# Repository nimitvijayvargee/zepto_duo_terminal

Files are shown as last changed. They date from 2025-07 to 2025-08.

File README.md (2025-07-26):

# zepto_duo_terminal
An old school-style VGA output terminal PC!
The PC is powered by two Raspberry Pi Picos. One of the Pico handles the main processing and the keyboard matrix (CPU Pico) and the other Pico handles the VGA Output and the conversion between text to pixels (GPU Pico). The Picos can be replaced with any Pin-compatible version.
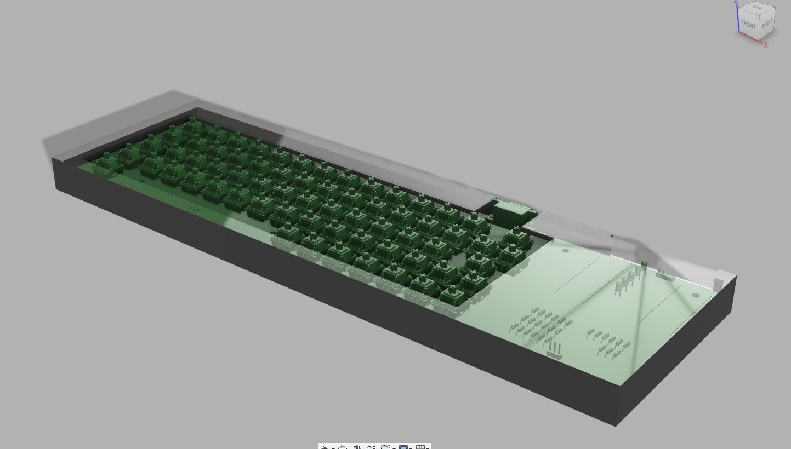
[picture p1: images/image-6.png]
Fusion Render

## VGA DAC
The GPU Pico is connected to a Resistor DAC that outputs VGA compatible voltage values. There are 5 bits of resolution for each colour channel (RGB555), which allows for 32K colours. The values for the DAC are as 500, 1K, 2K, and 5.1K (commonly used values).
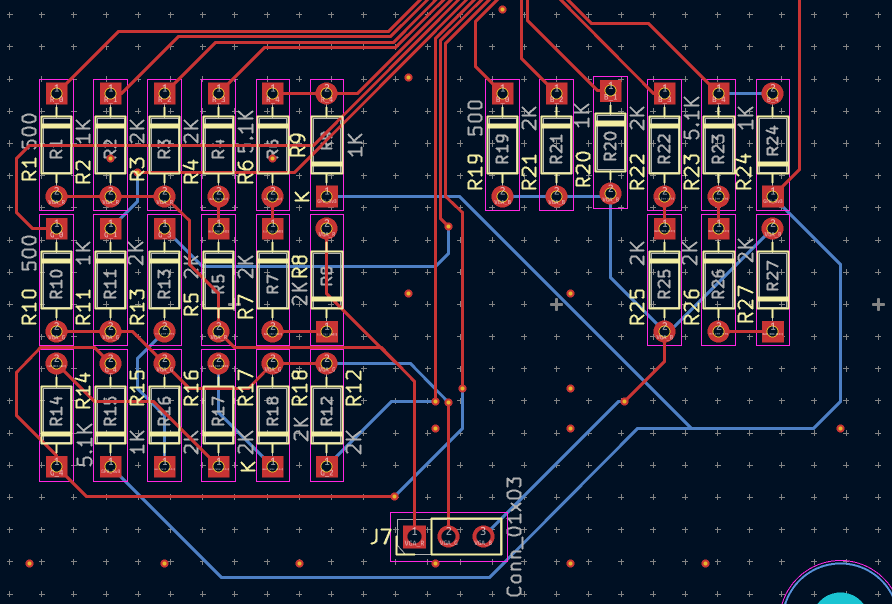
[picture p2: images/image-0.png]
VGADAC


## Keyboard Matrix 
The Keyboard matrix is composed of 8 Rows and 8 Columns, following an ortholinear keyboard layout. Sticky (toggle) keys is also enabled by default to make using the keyboard easier. The keyboard features a "Special" key instead of the commly used Fn or GUI keys. The keycaps are all custom becuase of their specific use case and the unorthodox ortholinear layout.

# Pictures
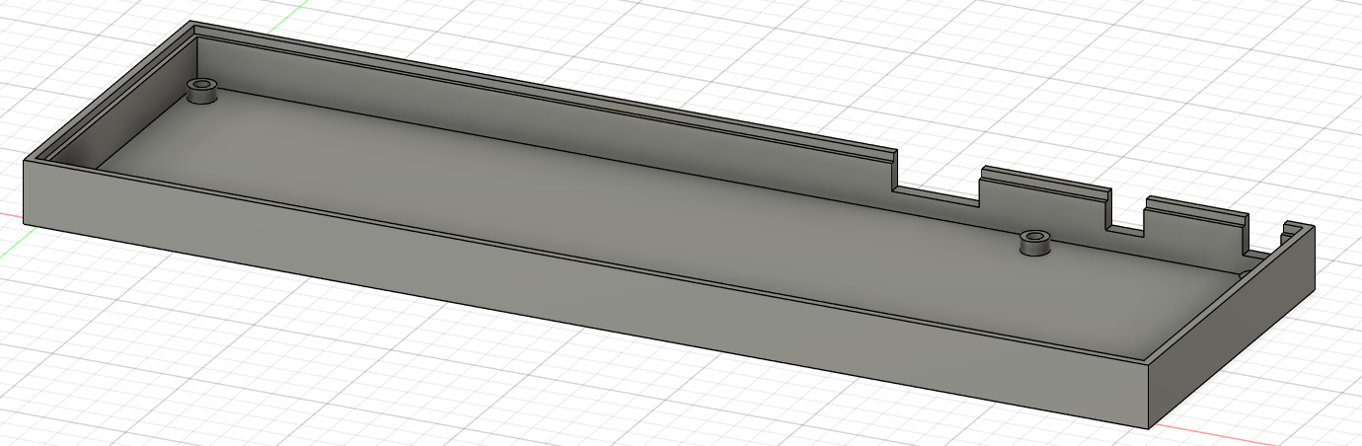
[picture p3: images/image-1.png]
Case

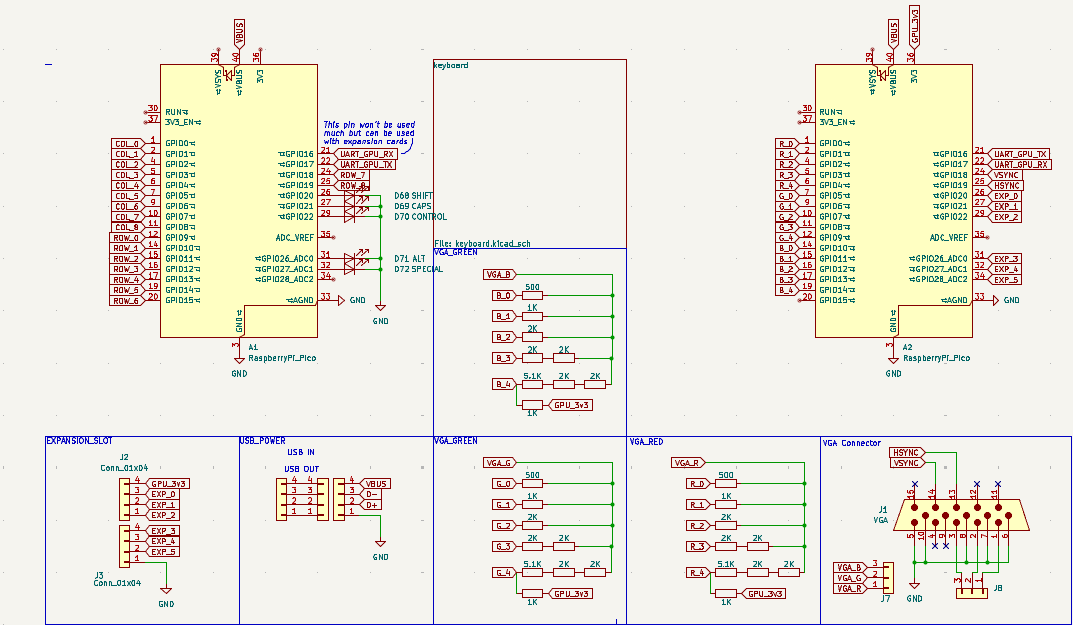
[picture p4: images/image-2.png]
Schematic

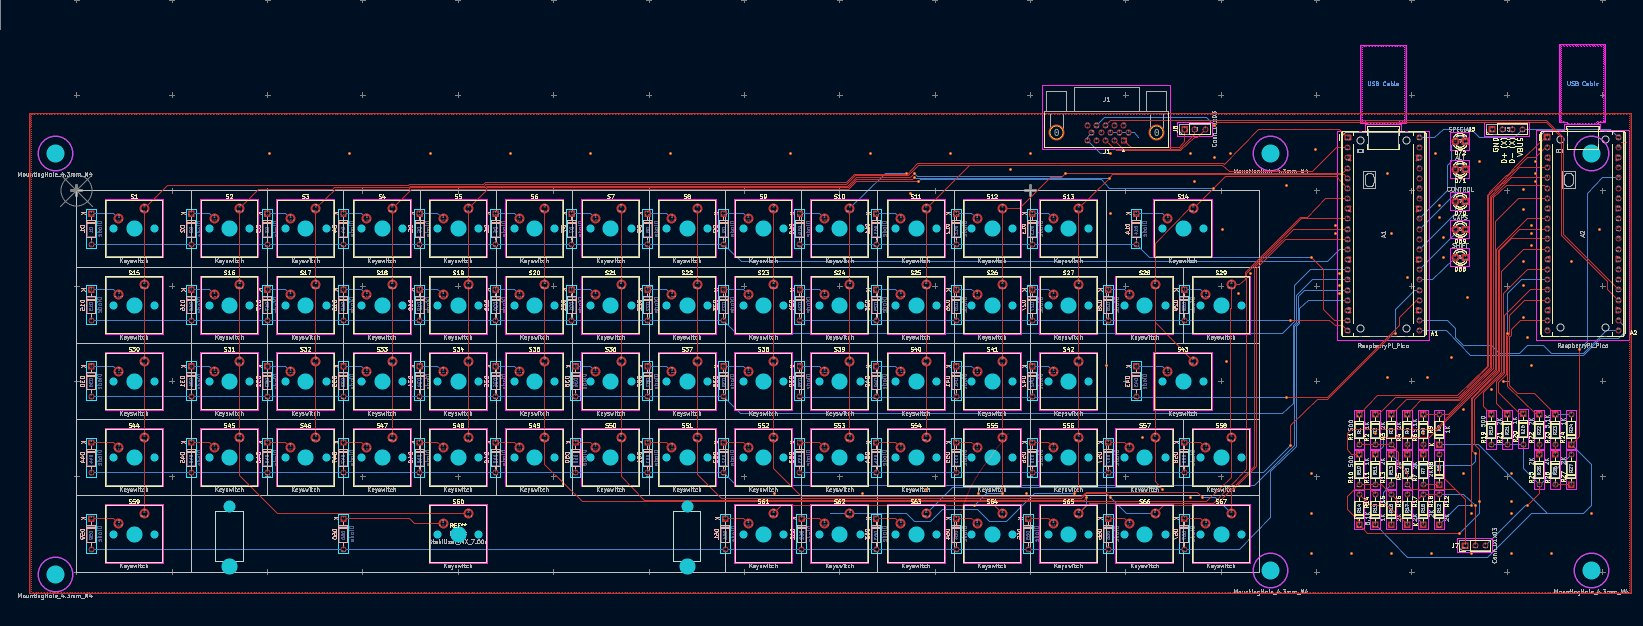
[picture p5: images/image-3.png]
PCB


# BOM
|Item |Cost|
|---|----|
|DB-15 VGA Connector |[1](https://roboticsdna.in/product/db15-female-pcb-mount-right-angle-connector-2-pcs/) |
|1N4148 Diodes |[5](https://roboticsdna.in/product/diode-1n4148/) |
|LEDs |[0.5](https://roboticsdna.in/product/super-bright-white-led-3mm-1000-pcs/) |
|Raspberry Pi Pico (x2)|[10](https://roboticsdna.in/product/raspberry-pi-pico/)  |
|Headers |[0.5](https://roboticsdna.in/product/40x1-10mm-2-5mm-pitch-burg-strip-male-straight-brass-high-quality-pack-of-5/) |
|PCB (400x120mm) |[75](https://www.pcbpower.com/page/pcb-fabrication)  |
|Case + Keycaps | |
|Switches |[20](https://stackskb.com/store/akko-v3-cream-blue-pro-switch-pack-of-45/)  |
|Solder |[5](https://roboticsdna.in/product/dl-premium-solder-wire-63-37-22-swg-50gm/)  |
|TOTAL |117 |

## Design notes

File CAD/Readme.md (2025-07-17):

The Case File is for the whole system
The keycap files are for each individual keycaps. 
| Keycap | Quantity |
|---|---|
| 1u | 59 |
| 1.5u | 5 |
| 2u | 2 |
| 7u | 1 |

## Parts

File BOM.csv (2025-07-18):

Item | Cost
DB-15 VGA Connector | 1
1N4148 Diodes | 5
LEDs | 0.5
Raspberry Pi Pico (x2) | 10
Headers | 0.5
PCB (400x120mm) | 75
Case + Keycaps
Switches | 20
Solder | 3
TOTAL | 115

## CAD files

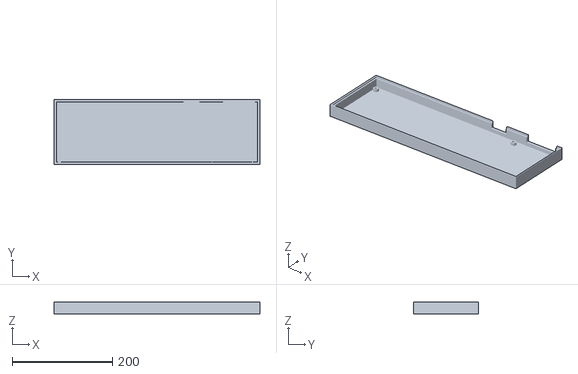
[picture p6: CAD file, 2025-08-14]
CAD/case.stl
410.0 x 130.0 x 23.0

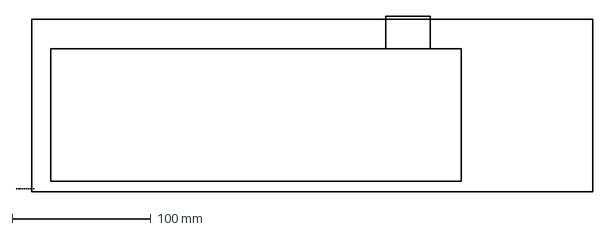
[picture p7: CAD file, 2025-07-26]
CAD/acrylic.dxf
415.0 x 126.0 mm

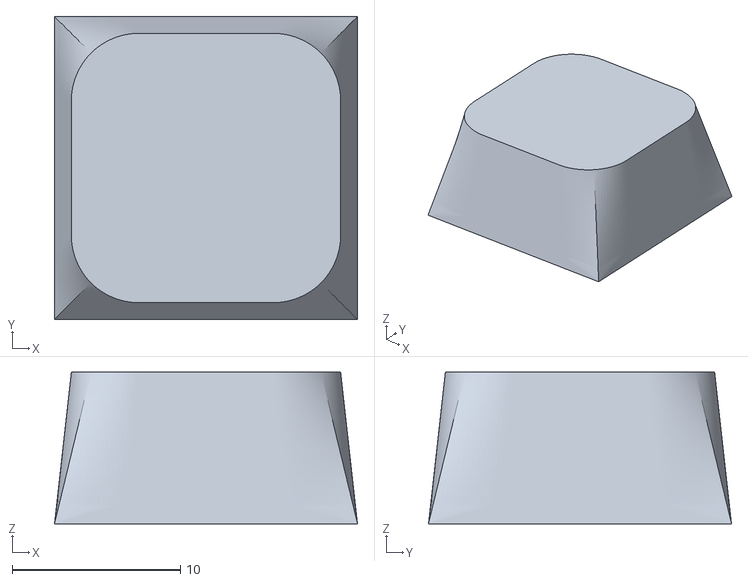
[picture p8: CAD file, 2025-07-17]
CAD/keycap1u.stl
18.0 x 18.0 x 9.00

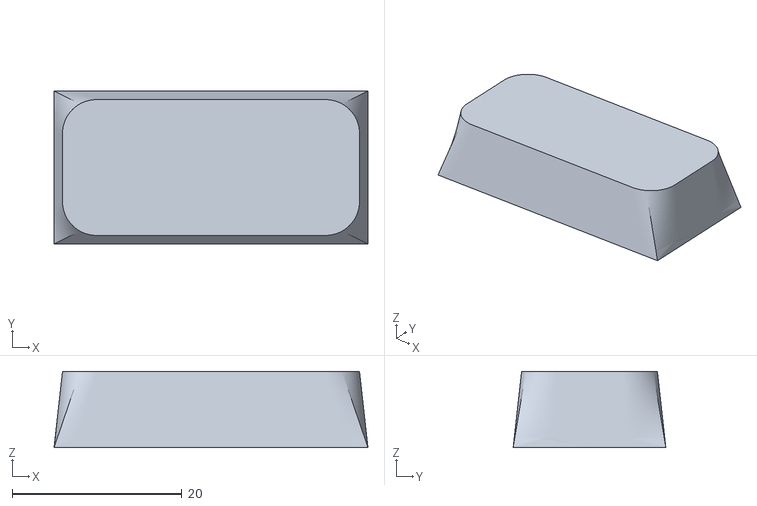
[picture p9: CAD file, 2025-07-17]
CAD/keycap2u.stl
37.0 x 18.0 x 9.00

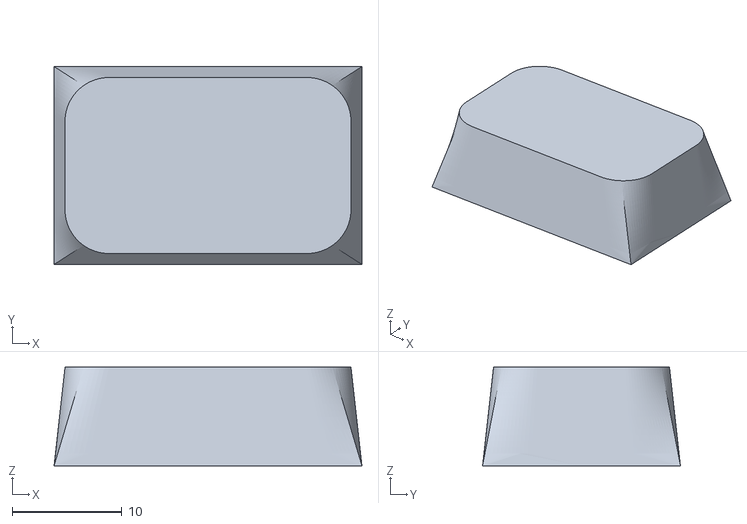
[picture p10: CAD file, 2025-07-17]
CAD/keycap1.5u.stl
28.0 x 18.0 x 9.00

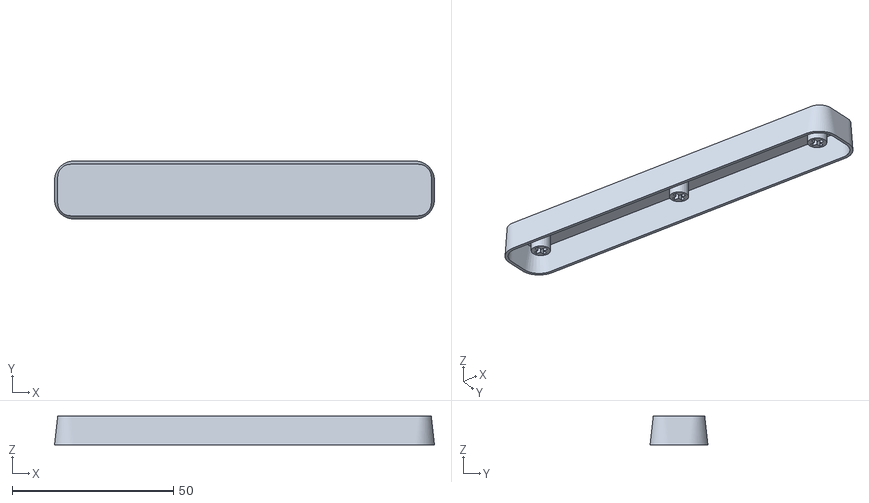
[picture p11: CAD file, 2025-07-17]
CAD/keycap7u.stl
118.0 x 18.0 x 9.00

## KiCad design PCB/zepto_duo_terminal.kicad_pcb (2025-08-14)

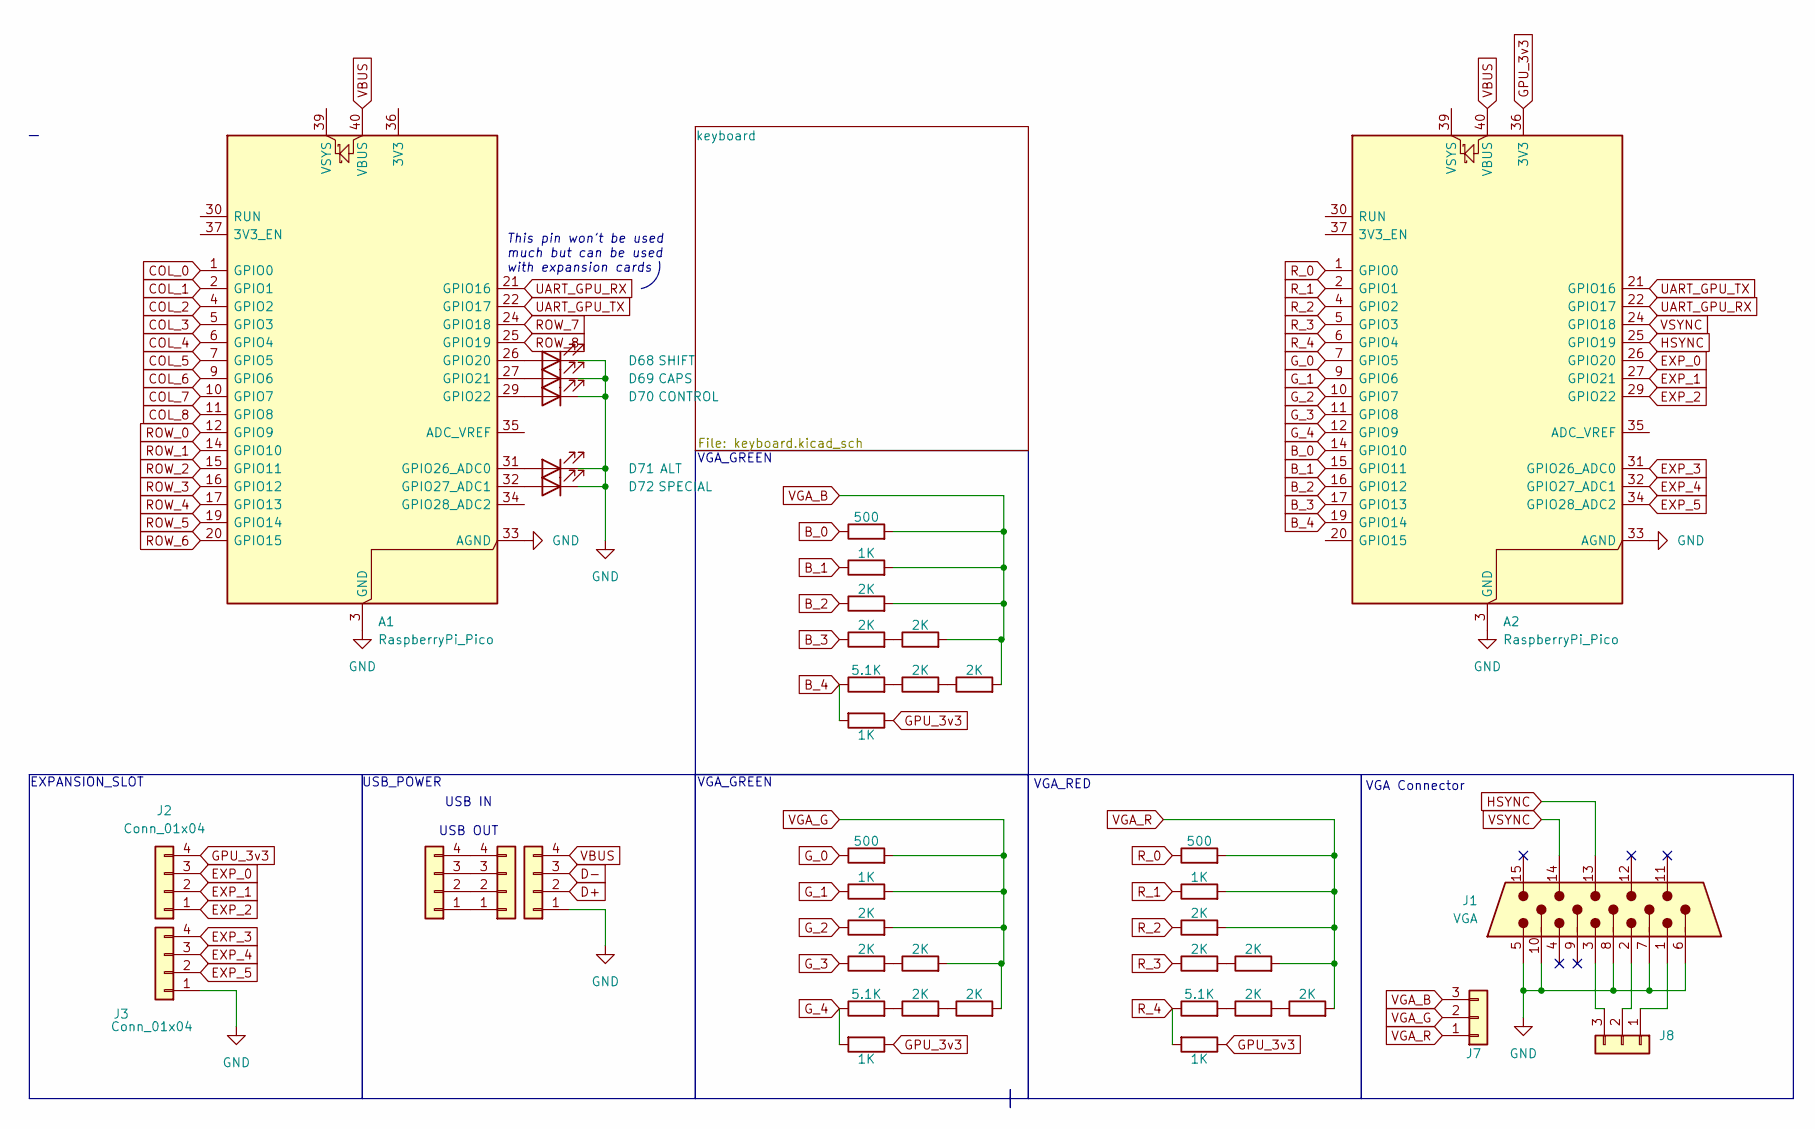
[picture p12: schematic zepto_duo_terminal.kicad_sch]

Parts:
A1, A2: RaspberryPi_Pico; RaspberryPi_Pico_Common_THT
D68: SHIFT; LED_D3.0mm
D69: CAPS; LED_D3.0mm
D70: CONTROL; LED_D3.0mm
D71: ALT; LED_D3.0mm
D72: SPECIAL; LED_D3.0mm
J1: VGA; DSUB-15-HD_Pins_Horizontal_P2.29x1.90mm_EdgePinOffset3.03mm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
J2, J3, J4, J5, J6: Conn_01x04; PinHeader_1x04_P2.54mm_Vertical
J7, J8: Conn_01x03; PinHeader_1x03_P2.54mm_Vertical
R1, R10, R19: 500; D_DO-35_SOD27_P7.62mm_Horizontal
R2, R9, R11, R15, R20, R24: 1K; D_DO-35_SOD27_P7.62mm_Horizontal
R3, R4, R5, R7, R8, R12, R13, R16, R17, R18, R21, R22, R25, R26, R27: 2K; D_DO-35_SOD27_P7.62mm_Horizontal
R6, R14, R23: 5.1K; D_DO-35_SOD27_P7.62mm_Horizontal

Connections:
B_0: A2.14 (GPIO10), R19.1
B_1: A2.15 (GPIO11), R20.1
B_2: A2.16 (GPIO12), R21.1
B_3: A2.17 (GPIO13), R22.1
B_4: A2.19 (GPIO14), R23.1, R24.2
COL_0: A1.1 (GPIO0); also elsewhere on the board
COL_1: A1.2 (GPIO1); also elsewhere on the board
COL_2: A1.4 (GPIO2); also elsewhere on the board
COL_3: A1.5 (GPIO3); also elsewhere on the board
COL_4: A1.6 (GPIO4); also elsewhere on the board
COL_5: A1.7 (GPIO5); also elsewhere on the board
COL_6: A1.9 (GPIO6); also elsewhere on the board
COL_7: A1.10 (GPIO7); also elsewhere on the board
COL_8: A1.11 (GPIO8); also elsewhere on the board
D+: J5.2
D-: J5.3
EXP_0: A2.26 (GPIO20), J2.3
EXP_1: A2.27 (GPIO21), J2.2
EXP_2: A2.29 (GPIO22), J2.1
EXP_3: A2.31 (GPIO26_ADC0), J3.4
EXP_4: A2.32 (GPIO27_ADC1), J3.3
EXP_5: A2.34 (GPIO28_ADC2), J3.2
GND: A1.3 (GND), A1.8 (GND), A1.13 (GND), A1.18 (GND), A1.23 (GND), A1.28 (GND), A1.33 (AGND), A1.38 (GND), A2.3 (GND), A2.8 (GND), A2.13 (GND), A2.18 (GND), A2.23 (GND), A2.28 (GND), A2.33 (AGND), A2.38 (GND), D68.1 (K), D69.1 (K), D70.1 (K), D71.1 (K), D72.1 (K), J1.5, J1.6, J1.7, J1.8, J1.10, J3.1, J5.1
GPU_3v3: A2.36 (3V3), J2.4, R9.1, R15.1, R24.1
G_0: A2.7 (GPIO5), R10.1
G_1: A2.9 (GPIO6), R11.1
G_2: A2.10 (GPIO7), R12.1
G_3: A2.11 (GPIO8), R13.1
G_4: A2.12 (GPIO9), R14.1, R15.2
HSYNC: A2.25 (GPIO19), J1.13
unnamed: A1.26 (GPIO20), D68.2 (A)
unnamed: A1.27 (GPIO21), D69.2 (A)
unnamed: A1.29 (GPIO22), D70.2 (A)
unnamed: A1.31 (GPIO26_ADC0), D71.2 (A)
unnamed: A1.32 (GPIO27_ADC1), D72.2 (A)
unnamed: J4.1, J6.1
unnamed: J4.2, J6.2
unnamed: J4.3, J6.3
unnamed: J4.4, J6.4
unnamed: J1.1, J8.1
unnamed: J1.2, J8.2
unnamed: J1.3, J8.3
unnamed: R4.2, R5.1
unnamed: R6.2, R7.1
unnamed: R7.2, R8.1
unnamed: R13.2, R16.1
unnamed: R14.2, R17.1
unnamed: R17.2, R18.1
unnamed: R22.2, R25.1
unnamed: R23.2, R26.1
unnamed: R26.2, R27.1
ROW_0: A1.12 (GPIO9); also elsewhere on the board
ROW_1: A1.14 (GPIO10); also elsewhere on the board
ROW_2: A1.15 (GPIO11); also elsewhere on the board
ROW_3: A1.16 (GPIO12); also elsewhere on the board
ROW_4: A1.17 (GPIO13); also elsewhere on the board
ROW_5: A1.19 (GPIO14); also elsewhere on the board
ROW_6: A1.20 (GPIO15); also elsewhere on the board
ROW_7: A1.24 (GPIO18); also elsewhere on the board
ROW_8: A1.25 (GPIO19); also elsewhere on the board
R_0: A2.1 (GPIO0), R1.1
R_1: A2.2 (GPIO1), R2.1
R_2: A2.4 (GPIO2), R3.1
R_3: A2.5 (GPIO3), R4.1
R_4: A2.6 (GPIO4), R6.1, R9.2
UART_GPU_RX: A1.21 (GPIO16), A2.22 (GPIO17)
UART_GPU_TX: A1.22 (GPIO17), A2.21 (GPIO16)
VBUS: A1.40 (VBUS), A2.40 (VBUS), J5.4
VGA_B: J7.3, R19.2, R20.2, R21.2, R25.2, R27.2
VGA_G: J7.2, R10.2, R11.2, R12.2, R16.2, R18.2
VGA_R: J7.1, R1.2, R2.2, R3.2, R5.2, R8.2
VSYNC: A2.24 (GPIO18), J1.14

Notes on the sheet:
VGA Connector
USB_POWER
USB IN USB OUT
VGA_RED
This pin won't be used much but can be used with expansion cards
EXPANSION_SLOT
VGA_GREEN

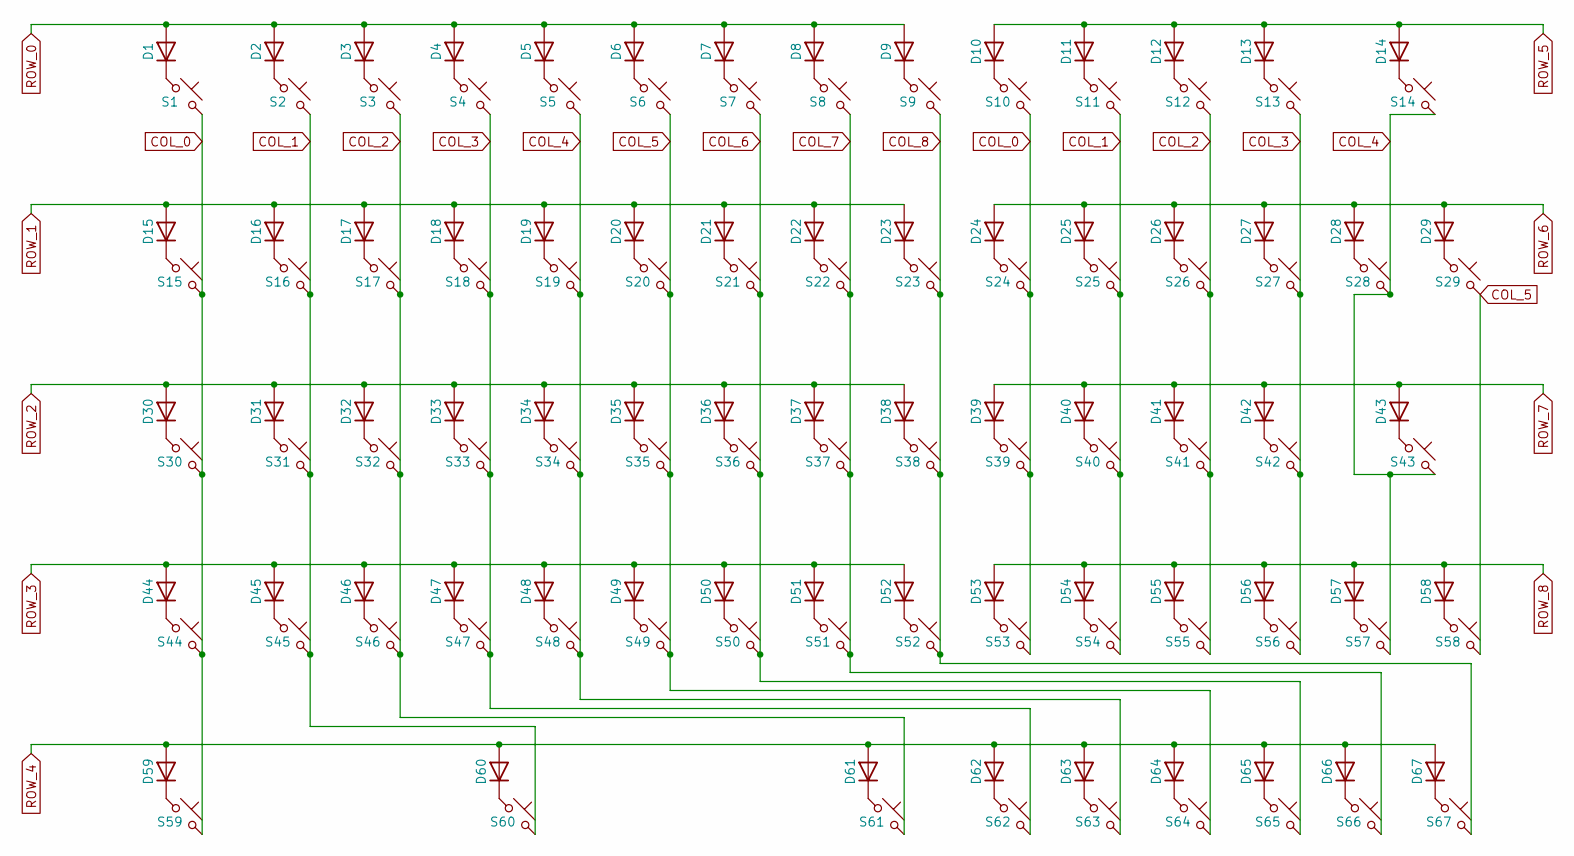
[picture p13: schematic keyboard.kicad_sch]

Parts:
D1, D2, D3, D4, D5, D6, D7, D8, D9, D10, D11, D12, D13, D14, D15, D16, D17, D18, D19, D20, D21, D22, D23, D24, D25, D26, D27, D28, D29, D30, D31, D32, D33, D34, D35, D36, D37, D38, D39, D40, D41, D42, D43, D44, D45, D46, D47, D48, D49, D50, D51, D52, D53, D54, D55, D56, D57, D58, D59, D60, D61, D62, D63, D64, D65, D66, D67: Diode; D_DO-35_SOD27_P7.62mm_Horizontal
S1, S15, S30, S44, S59: Keyswitch; MX_PCB_1.50u
S2, S3, S4, S5, S6, S7, S8, S9, S10, S11, S12, S13, S16, S17, S18, S19, S20, S21, S22, S23, S24, S25, S26, S27, S28, S29, S31, S32, S33, S34, S35, S36, S37, S38, S39, S40, S41, S42, S45, S46, S47, S48, S49, S50, S51, S52, S53, S54, S55, S56, S57, S58, S62, S63, S64, S65, S66, S67: Keyswitch; MX_PCB_1.00u
S14, S43: Keyswitch; MX_PCB_2.00u
S60: Keyswitch; MX_PCB_6.25u
S61: Keyswitch; MX_PCB_1.25u

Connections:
COL_0: S1.2, S10.2, S15.2, S24.2, S30.2, S39.2, S44.2, S53.2, S59.2; also elsewhere on the board
COL_1: S2.2, S11.2, S16.2, S25.2, S31.2, S40.2, S45.2, S54.2, S60.2; also elsewhere on the board
COL_2: S3.2, S12.2, S17.2, S26.2, S32.2, S41.2, S46.2, S55.2, S61.2; also elsewhere on the board
COL_3: S4.2, S13.2, S18.2, S27.2, S33.2, S42.2, S47.2, S56.2, S62.2; also elsewhere on the board
COL_4: S5.2, S14.2, S19.2, S28.2, S34.2, S43.2, S48.2, S57.2, S63.2; also elsewhere on the board
COL_5: S6.2, S20.2, S29.2, S35.2, S49.2, S58.2, S64.2; also elsewhere on the board
COL_6: S7.2, S21.2, S36.2, S50.2, S65.2; also elsewhere on the board
COL_7: S8.2, S22.2, S37.2, S51.2, S66.2; also elsewhere on the board
COL_8: S9.2, S23.2, S38.2, S52.2, S67.2; also elsewhere on the board
unnamed: D1.1 (K), S1.1
unnamed: D2.1 (K), S2.1
unnamed: D3.1 (K), S3.1
unnamed: D4.1 (K), S4.1
unnamed: D5.1 (K), S5.1
unnamed: D6.1 (K), S6.1
unnamed: D7.1 (K), S7.1
unnamed: D8.1 (K), S8.1
unnamed: D9.1 (K), S9.1
unnamed: D10.1 (K), S10.1
unnamed: D11.1 (K), S11.1
unnamed: D12.1 (K), S12.1
unnamed: D13.1 (K), S13.1
unnamed: D14.1 (K), S14.1
unnamed: D15.1 (K), S15.1
unnamed: D16.1 (K), S16.1
unnamed: D17.1 (K), S17.1
unnamed: D18.1 (K), S18.1
unnamed: D19.1 (K), S19.1
unnamed: D20.1 (K), S20.1
unnamed: D21.1 (K), S21.1
unnamed: D22.1 (K), S22.1
unnamed: D23.1 (K), S23.1
unnamed: D24.1 (K), S24.1
unnamed: D25.1 (K), S25.1
unnamed: D26.1 (K), S26.1
unnamed: D27.1 (K), S27.1
unnamed: D28.1 (K), S28.1
unnamed: D29.1 (K), S29.1
unnamed: D30.1 (K), S30.1
unnamed: D31.1 (K), S31.1
unnamed: D32.1 (K), S32.1
unnamed: D33.1 (K), S33.1
unnamed: D34.1 (K), S34.1
unnamed: D35.1 (K), S35.1
unnamed: D36.1 (K), S36.1
unnamed: D37.1 (K), S37.1
unnamed: D38.1 (K), S38.1
unnamed: D39.1 (K), S39.1
unnamed: D40.1 (K), S40.1
unnamed: D41.1 (K), S41.1
unnamed: D42.1 (K), S42.1
unnamed: D43.1 (K), S43.1
unnamed: D44.1 (K), S44.1
unnamed: D45.1 (K), S45.1
unnamed: D46.1 (K), S46.1
unnamed: D47.1 (K), S47.1
unnamed: D48.1 (K), S48.1
unnamed: D49.1 (K), S49.1
unnamed: D50.1 (K), S50.1
unnamed: D51.1 (K), S51.1
unnamed: D52.1 (K), S52.1
unnamed: D53.1 (K), S53.1
unnamed: D54.1 (K), S54.1
unnamed: D55.1 (K), S55.1
unnamed: D56.1 (K), S56.1
unnamed: D57.1 (K), S57.1
unnamed: D58.1 (K), S58.1
unnamed: D59.1 (K), S59.1
unnamed: D60.1 (K), S60.1
unnamed: D61.1 (K), S61.1
unnamed: D62.1 (K), S62.1
unnamed: D63.1 (K), S63.1
unnamed: D64.1 (K), S64.1
unnamed: D65.1 (K), S65.1
unnamed: D66.1 (K), S66.1
unnamed: D67.1 (K), S67.1
ROW_0: D1.2 (A), D2.2 (A), D3.2 (A), D4.2 (A), D5.2 (A), D6.2 (A), D7.2 (A), D8.2 (A), D9.2 (A); also elsewhere on the board
ROW_1: D15.2 (A), D16.2 (A), D17.2 (A), D18.2 (A), D19.2 (A), D20.2 (A), D21.2 (A), D22.2 (A), D23.2 (A); also elsewhere on the board
ROW_2: D30.2 (A), D31.2 (A), D32.2 (A), D33.2 (A), D34.2 (A), D35.2 (A), D36.2 (A), D37.2 (A), D38.2 (A); also elsewhere on the board
ROW_3: D44.2 (A), D45.2 (A), D46.2 (A), D47.2 (A), D48.2 (A), D49.2 (A), D50.2 (A), D51.2 (A), D52.2 (A); also elsewhere on the board
ROW_4: D59.2 (A), D60.2 (A), D61.2 (A), D62.2 (A), D63.2 (A), D64.2 (A), D65.2 (A), D66.2 (A), D67.2 (A); also elsewhere on the board
ROW_5: D10.2 (A), D11.2 (A), D12.2 (A), D13.2 (A), D14.2 (A); also elsewhere on the board
ROW_6: D24.2 (A), D25.2 (A), D26.2 (A), D27.2 (A), D28.2 (A), D29.2 (A); also elsewhere on the board
ROW_7: D39.2 (A), D40.2 (A), D41.2 (A), D42.2 (A), D43.2 (A); also elsewhere on the board
ROW_8: D53.2 (A), D54.2 (A), D55.2 (A), D56.2 (A), D57.2 (A), D58.2 (A); also elsewhere on the board

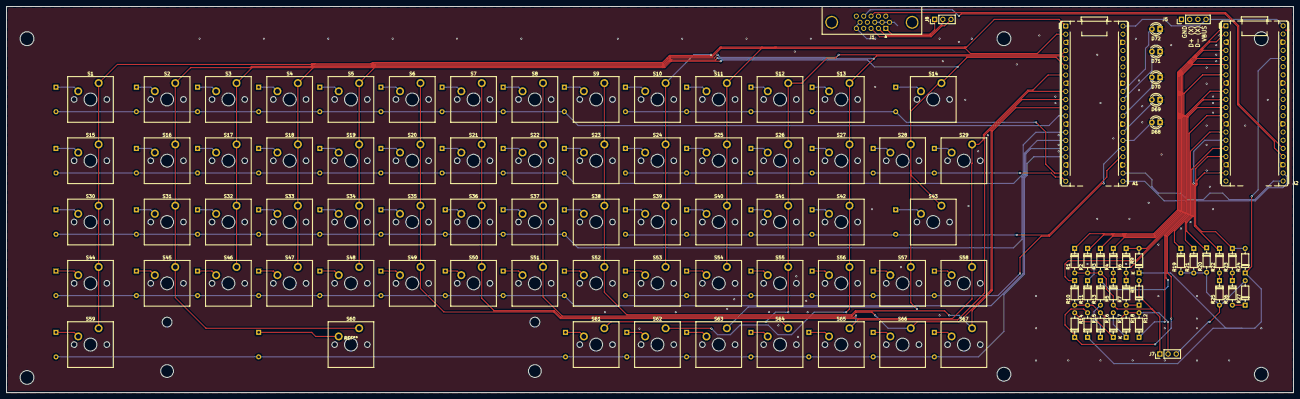
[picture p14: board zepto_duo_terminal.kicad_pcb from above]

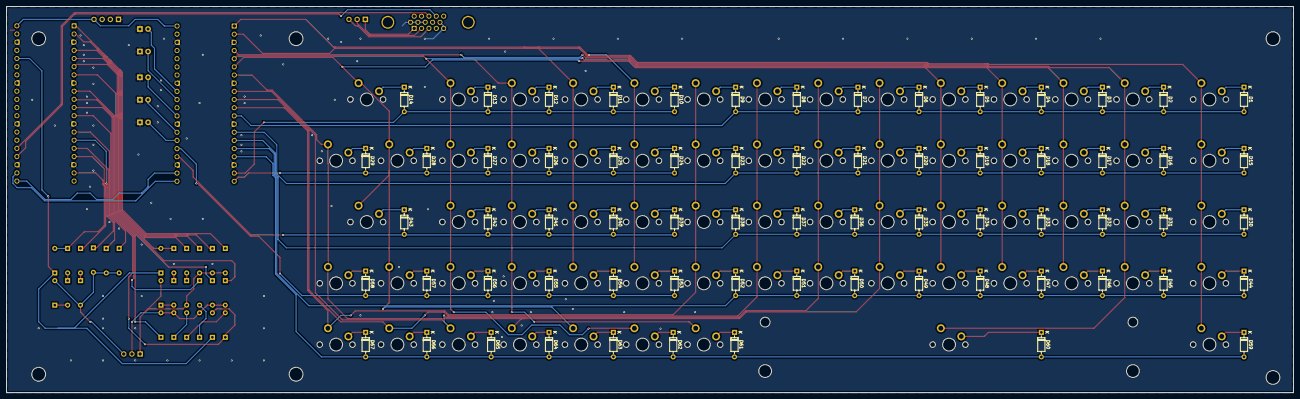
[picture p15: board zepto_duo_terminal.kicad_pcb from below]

Board: 2 copper layers, 400.0 x 120.0 mm, 172 parts (67 on the bottom side), 127 nets.

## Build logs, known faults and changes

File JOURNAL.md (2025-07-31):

---
title: "Zepto Duo Terminal"
author: "nimit vijayvargee"
description: "An all-in-one Terminal PC with two Pi Picos that outputs VGA, all with a a built-in keyboard!"
created_at: "2025-06-24"
---
# Total Time Spent : 26 Hours

# Day 1 - 25th June
Created a sketch and layout for the project, mostly brainstorming

# Day 2 - 26th June
Time Spent: 2hrs <br>
Started reseasrching into VGA with the Pi Pico, and read the Hardware Design docs for VGA pinouts and connections.
The RP2040 Hardware Design docs dedicate a section to the VGA interface over PIO Assembly. After doing some research, I found out about `scanvideo`, which is a Pico SDK PIO Library for implementing scanline video output such as DVI and VGA, which is exactly what I need.


# Day 3 - 27th June
Time Spent: 2hrs <br>
Designed the built-in keyboard, plan to use basic MX keys with an ortholinear layout. Also included sticky-keys indicators because holding keys simultaneously may be difficult to implement. Also laid out the keyboard both in Keyboard Layout Editor. I then added everything to the schematic which was very easy due to the ortholinear keyboard layout. I managed to connect the GPU and CPU Picos over a data bridge, which I intend to be UART.<br>


Time Spent: 3hrs <br>
Today I completed routing the schematic. I also managed to finish laying out the keyboard design and connected all the rows and columns. I then spent some time choosing the footprints for all the components. This PCB is intended to be hand-soldered so I chose THT footprints for the Diodes, Resistors and the LEDs. Because of the custom layout, I was unable to find any useful keycaps (I mean who makes a 1u shift key and a 1.5u escape key), so I will be 3D printing the keycaps. I also designed a few sketches for how I want the case to look like. I want it to be a two-part case, with the top part being acrylic and the bottom part being 3D printed. This will make the green PCB look very cool and show all the various components.



# Day 4 - Day 8 -- 28th June - 1st July 
Time Spent: 8hrs
I placed the footprints into my PCB editor and started moving them around. I added M4 Screw holes for the PCB to attach to the case. I added a header for an expansion slot for later use although I might scrap the feature altogether. I laid out the matrix and the diodes using the MX Grid trick (set your grid size to match the MX size). I also added a little bit of silkscreen to make the PCB have some personality.



# Day 9 - Day 10 -- 2nd July - 3rd July
Time Spent: 3hrs
I rerouted the PCB and moved around the components to make it more compact. I also planned out the keycaps to print. I initially planned to use a 6.25u Spacebar, but since it is the only key that needs that stabilizer, I decided to use a 7u spacebar instead, because I had an extra 7u wire. I managed to redo the layout and routing to accommodate the 7u, which wasn't as hard. I also considered printing the keycaps in offwhite PLA but it isn't as easy to find as black or white, so I will stick to those for now.

# Day 11 - Day 12 -- 10th July - 11th July
Time Spent: 3hrs <br>
Returned to this project after some time. On comparing prices across websites, it was much cheaper to reroute the main board to follow a different layout. The board is now 400x120 (mm) and has more or a Pi500 vibe to it. Most of the layout and routing could be reused but I did decide to redo the resistors for the VGA and remove the expansion card slot



# Day 13 - 14th July
Time Spent: 2hrs <br>
I started working on the CAD. I first sketched out the PCB with the mounting holes then created an area arount it. I extruded everything to a reasonable size and created some renders. I just need to make the keycpas now.

# Day 14 - 15 -- 15th - 16th July
Time Spent: 2hrs <br>
I spent this day just designing the custom keycaps. It was difficult but  when I finished my first 1u keycap, I got into the pace to finish the rest of the keycaps too. The 7u spacebar looks a bit weird but I kinda like the idea of a curved spacebar alongside normal keys. The rounded corners are just somethinng I want to do, although they might attract dust (future me problem lol). \





# Day 15 - 27th July
Time Spent: 1hr <br>
I worked on the code. I am going to use the `adafruit_color_terminal` library for circuitpython to create the terminal, but for the video output I need to decide between `scanvideo` (C SDK) or writing it in PIO-ASM on Circuitpython. I did some testing of the code on a spare ST7735R screen I had lying around. Afterwards, I can do it properly on a monitor.
I also made a render for the updated case!


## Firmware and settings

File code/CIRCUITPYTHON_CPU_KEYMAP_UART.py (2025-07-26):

import keypad
import digitalio
import board
import busio

# This part of the code just takes the input from a keypad attached and
# outputs it via a UART bus into another pico (the GPU) which handles
# displaying it. This is testing code.
# The main code will involve passing the key-inputs through a REPL or
# text-based code editor, which is passed to the GPU. That way, the code
# can be executed on this device, while the output is transferred to the
# other video handler.

uart = busio.UART(tx=board.GP16, rx=board.GP17, baudrate=9600)
km = keypad.KeyMatrix(
    row_pins=(board.GP0, board.GP1, board.GP2, board.GP3, board.GP4, board.GP5, board.GP6, board.GP7, board.GP8),
    column_pins=(board.GP9, board.GP10, board.GP11, board.GP12, board.GP13, board.GP14, board.GP15, board.GP16),
    columns_to_anodes=False
)
map = [
    ["esc", "1", "2", "3", "4", "5", "6", "7", "8"],
    ["tab", "q", "w", "e", "r", "t", "y", "u", "i"],
    ["caps","a", "s", "d", "f", "g", "h", "j", "k"],
    ["shift","z","x", "c", "v", "b", "n", "m", "<"],
    ["ctrl","space", "ctrl", "special", "alt", "up", "down", "left", "right"],
    ["9", "0","-","=","back"],
    ["o", "p", "[","]","\\", "|" ],
    ["l",";","\"","enter"],
    [">", ",", ".", "?", "`", "shift"]
]
while True:
    event = km.events.get()
    if event and event.pressed:
        row = event.key_number // len(km.column_pins)
        col = event.key_number % len(km.column_pins)
        keyname = map[col][row]
        uart.write((keyname + "\n").encode("utf-8")) # output to UART bus for GPU to handle

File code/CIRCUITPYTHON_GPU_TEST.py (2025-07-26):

import supervisor
from displayio import Group, release_displays
from terminalio import FONT
from adafruit_st7735r import ST7735R
from fourwire import FourWire
from adafruit_color_terminal import ColorTerminal
import board
import busio


release_displays()

spi = busio.SPI(clock=board.GP18, MOSI=board.GP19)
tft_cs = board.GP20
tft_dc = board.GP16

display_bus = FourWire(spi, command=tft_dc, chip_select=tft_cs, reset=board.GP17)

display = ST7735R(display_bus, width=160, height=128, rotation=90, bgr=True)

main_group = Group()
font_bb = FONT.get_bounding_box()
terminal = ColorTerminal(FONT, 26, 10)
main_group.append(terminal.tilegrid)

green = chr(27) + "[32m"

message = f"{green}Zepto Duo Terminal"
terminal.write(message)
print(message, end="\n\n\n\n\n\n\n\n")

while True:
    pass

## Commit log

2025-07-17 Complete README and CAD
    [case.stl, keyboard.kicad_sch, keycap1.5u.stl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]
2025-07-31 Fixed Gerbers
    [zepto_duo_terminal.kicad_pcb]
2025-08-14 Minor changes to case and PCB
    [case.stl, zepto_duo_terminal.kicad_pcb]
